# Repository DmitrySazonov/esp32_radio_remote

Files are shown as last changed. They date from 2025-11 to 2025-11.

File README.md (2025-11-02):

# ESP32 Radio Remote

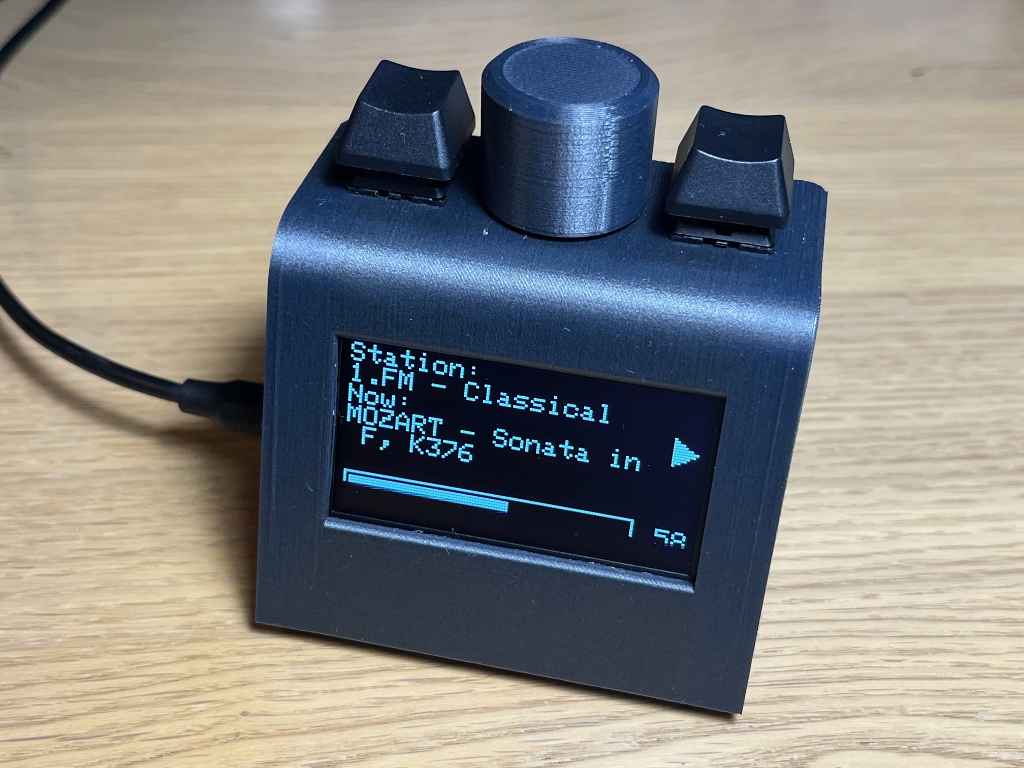
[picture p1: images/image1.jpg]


Small ESP32-based remote for controlling a phone radio/streaming app [Flutter radio](https://github.com/DmitrySazonov/flutter_radio) over HTTP.
It shows station and “now playing” on a 128×64 SSD1306 OLED, has an encoder for volume and play/pause, dedicated Prev/Next buttons, night dimming, and a Screen Off idle timer. A built-in web page lets you configure Wi-Fi and behavior without reflashing.

## Repository Layout

```bash
.
├─ fritzing/     # Fritzing schematic (.fzz) + exported image(s)
├─ stl/          # 3D-printable case parts
└─ esp32-radio-remote.ino  # main Arduino sketch
```

## Features (quick list)

- Encoder: rotate = volume (with optional acceleration), press:
  - single click = Play/Pause
  - rotate while pressed = Station tuning (Prev/Next)
- Buttons: dedicated Prev and Next GPIO buttons
- OLED UI: station title + now playing, volume bar, optional Wi-Fi badge (STA/AP)
- Night mode: dim to a low brightness after inactivity
- Screen Off: fully power down the OLED after a longer timeout
- Web UI (STA/AP): configure Wi-Fi SSID/Password, app host/port/token, scrolling, brightness levels, and more

- Resilience:
  - If Wi-Fi is down: device switches to AP config portal
  - If phone/app is unreachable: shows Phone offline. Retry connection... and retries with growing timeouts (up to 10s), then continues polling

## Hardware

- MCU: ESP32 DevKit (ESP-WROOM-32 or similar)
- Display: SSD1306 128×64 (I²C, address 0x3C)
- Encoder: 2-bit incremental with push button
- Buttons: two momentary buttons for Prev and Next

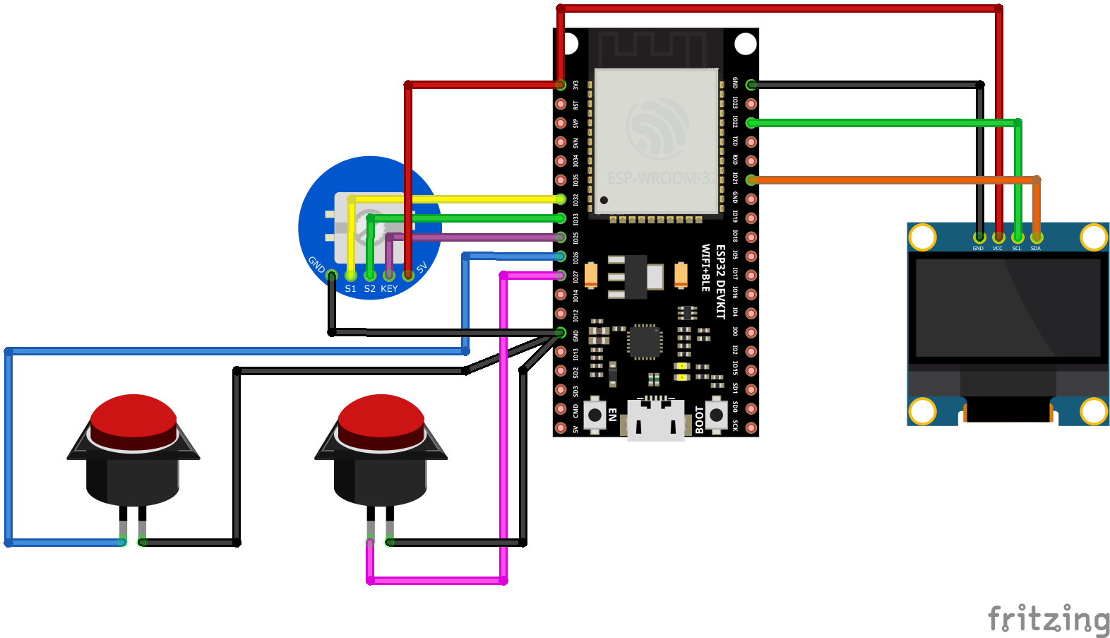
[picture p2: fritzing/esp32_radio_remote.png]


See fritzing/ for exact wiring (.fzz) and a PNG preview.
STL files for the enclosure live in stl/.

### Default pins (can be edited in the sketch):

- Encoder: CLK 32, DT 33, SW 25
- I²C: SDA 21, SCL 22
- Prev/Next: 26, 27 (wired to GND, use INPUT_PULLUP)

## Requirements

- Arduino IDE (2.x recommended)
- ESP32 core by Espressif (Boards Manager)
- Libraries (Library Manager):
  - Adafruit SSD1306
  - Adafruit GFX Library
  - ArduinoJson
  - (Included with ESP32 core: ESPmDNS, DNSServer, ArduinoOTA)

## Installation & Flashing (Arduino IDE)

1. Install ESP32 support

   - File → Preferences → “Additional Boards Manager URLs”: 
   https://raw.githubusercontent.com/espressif/arduino-esp32/gh-pages/package_esp32_index.json
   - Tools → Board → Boards Manager… → install esp32 by Espressif Systems.
     
2. Install libraries
   - Tools → Manage Libraries…
   - Search & install: Adafruit SSD1306, Adafruit GFX Library, ArduinoJson.

3. Open the sketch
    - File → Open… → select esp32-radio-remote.ino in repo root.

4. Select your board & port
   - Tools → Board: choose your ESP32 (e.g., ESP32 Dev Module or your exact variant).
   - Tools → Port: pick the COM/tty of your ESP32.

5. Compile & Upload
   - Sketch → Upload (or the right-arrow button).
   - (Optional) open Tools → Serial Monitor at 115200 baud to see boot logs.

📝 You don’t need to hardcode your Wi-Fi or phone host in the code. After the first boot, the device exposes a Config Portal in AP mode.

## First Boot & Config Portal

 - On the very first boot (or when your configured Wi-Fi is unavailable), the device enters AP mode:
   - SSID: RadioRemote-XXXXXXXX (based on MAC)
   - Password: 12345678
   - Open http://192.168.4.1/
 - After saving, it reboots and tries connecting to your Wi-Fi and your phone app.

Tip: In STA mode you can also try http://radio-remote.local/ or use the device IP (triple-click the encoder to show IP/SSID on OLED).

## Web UI — Settings Explained

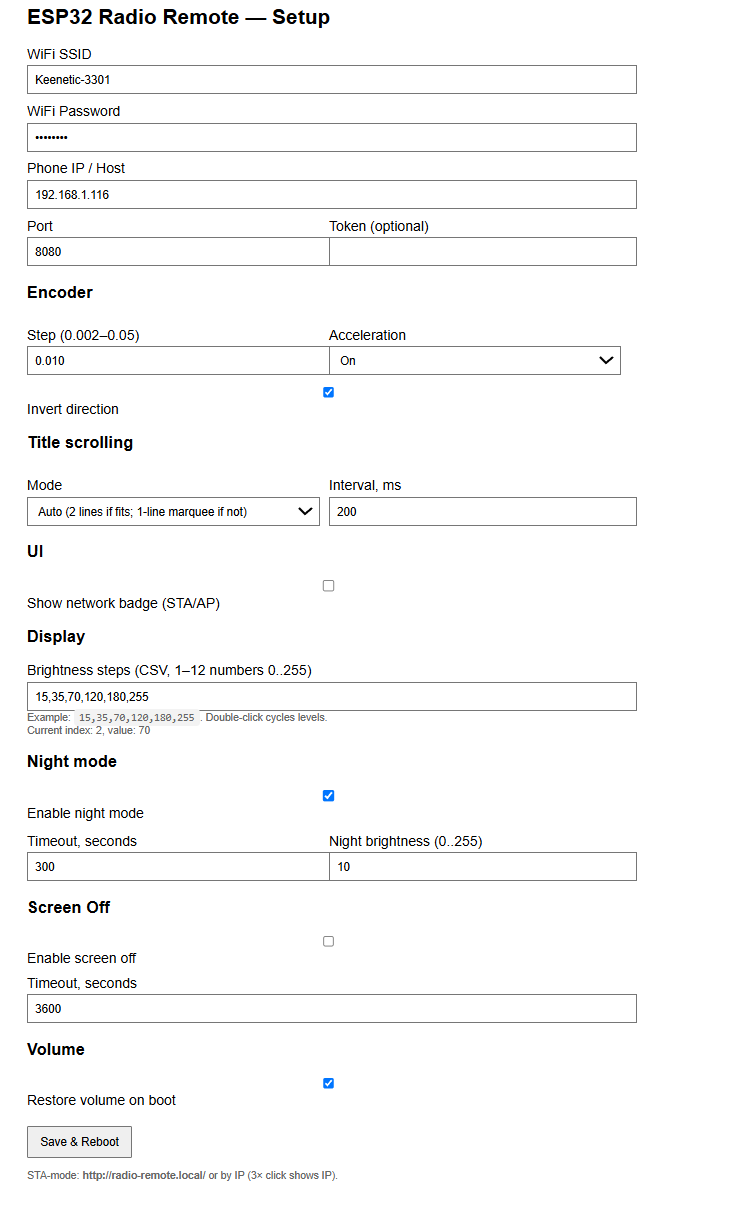
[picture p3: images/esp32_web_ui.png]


Open the device IP in a browser (or http://radio-remote.local/).

### Wi-Fi & Phone App
- WiFi SSID / Password — your network credentials.
- Phone IP / Host — hostname or IP of the phone running the radio/streaming app (the device calls your app’s HTTP endpoints).
- Port — HTTP port of the app (default 8080).
- Token (optional) — if your app expects a token query parameter, it will be appended automatically to every request.

### Encoder
- Step (0.002–0.05) — volume increment per detent (float, e.g. 0.01).
- Acceleration — increases step temporarily when you spin the knob fast.
- Invert direction — flips the volume/tuning direction.

### Title Scrolling
- Mode:
  - Off — never scroll; up to 2 lines are shown if they fit.
  - Auto — if text overflows, use one-line marquee; otherwise 2 lines.
  - Always marquee — always scroll as a single line.
- Interval, ms — scrolling speed (e.g., 200 ms).

### UI
- Show network badge (STA/AP) — small status box in the top-right corner:
  - Mode: STA or AP
  - RSSI indicator (++, + , or - ) if connected

### Display
- Brightness steps (CSV) — comma-separated list of OLED brightness levels (0..255), sorted and deduplicated automatically.
Example: 15,35,70,120,180,255 

Double-click the encoder to cycle levels.

### Night mode
- Enable night mode — after inactivity, dim the screen.
- Timeout, seconds — inactivity period before dimming.
- Night brightness (0..255) — target dim value.

### Screen Off
- Enable screen off — after longer inactivity, power down the OLED.
- Timeout, seconds — inactivity period before complete off (e.g., 3600).

### Volume
- Restore volume on boot — remember last volume and apply after restart.

### Save & Reboot
- Save & Reboot — writes settings to flash and reboots.
A small auto-redirect page returns you to / after the device comes back.

## On-Device Controls (OLED & Buttons)
- Encoder rotate: volume
- Encoder single click: play/pause
- Encoder rotate while held: station tuning (Prev/Next)
- Double click: cycle brightness levels
- Triple click: show network info (IP/SSID) overlay
- Prev/Next buttons: change station immediately

### Status messages on OLED
- If Wi-Fi is unavailable (no IP): device switches to AP mode and shows config hints.
- If phone/app is unreachable (Wi-Fi OK but HTTP fails): display only

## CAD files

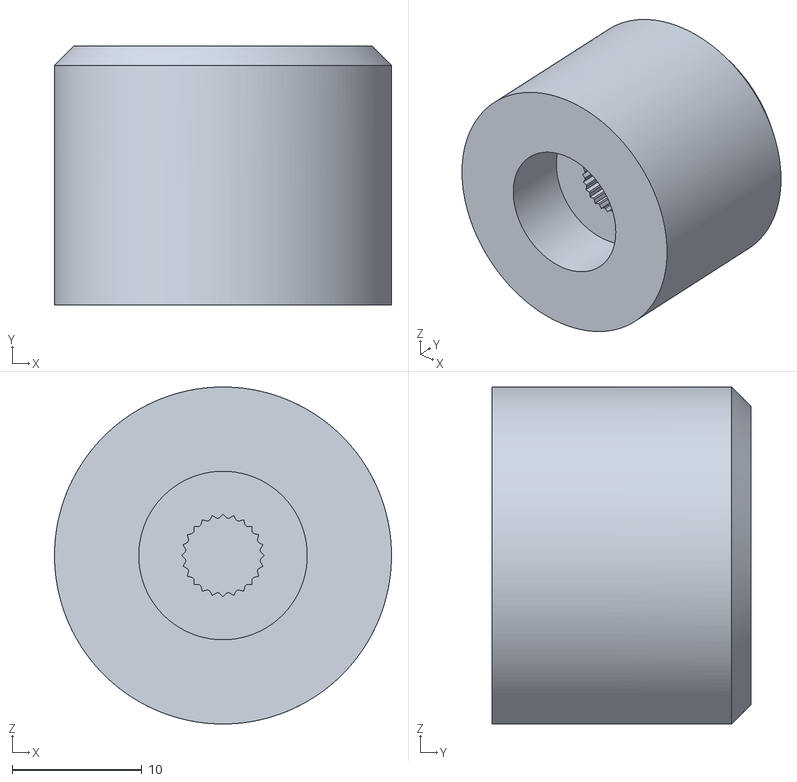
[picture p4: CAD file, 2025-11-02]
stl/encoder-knob.stl
26.0 x 20.0 x 26.0

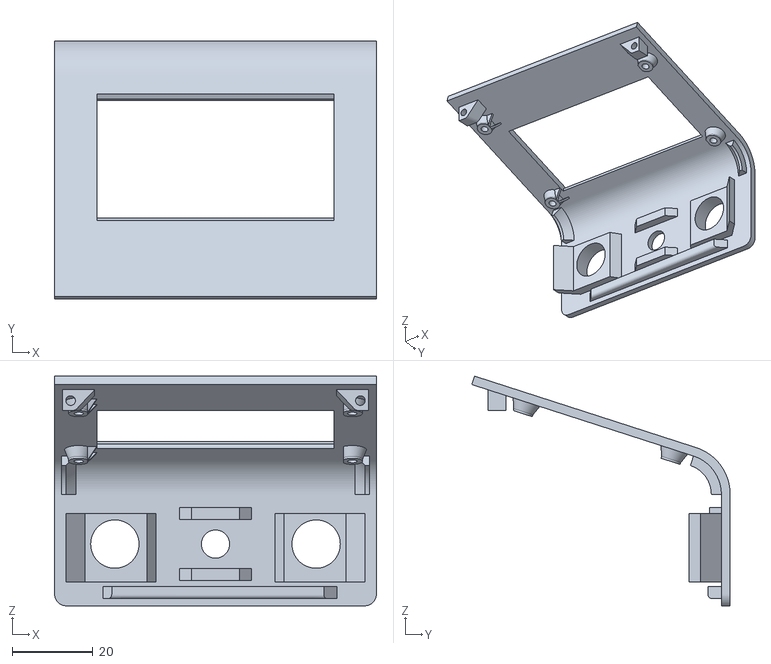
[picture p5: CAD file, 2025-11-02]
stl/cap 1.1.stl
80.0 x 64.2 x 57.1

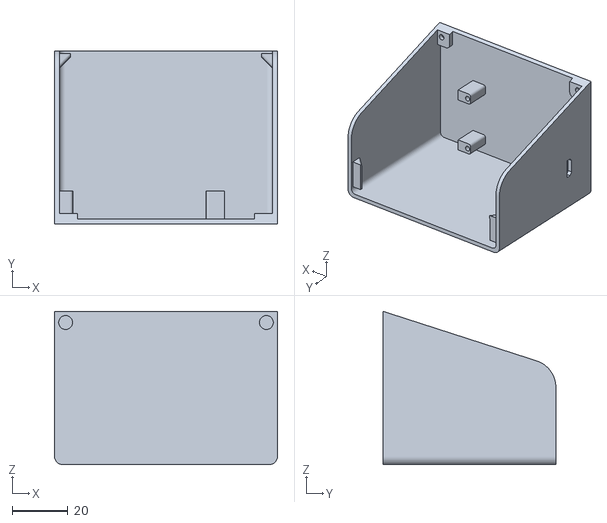
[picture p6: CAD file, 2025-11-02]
stl/case 1.1.stl
80.0 x 62.0 x 55.0

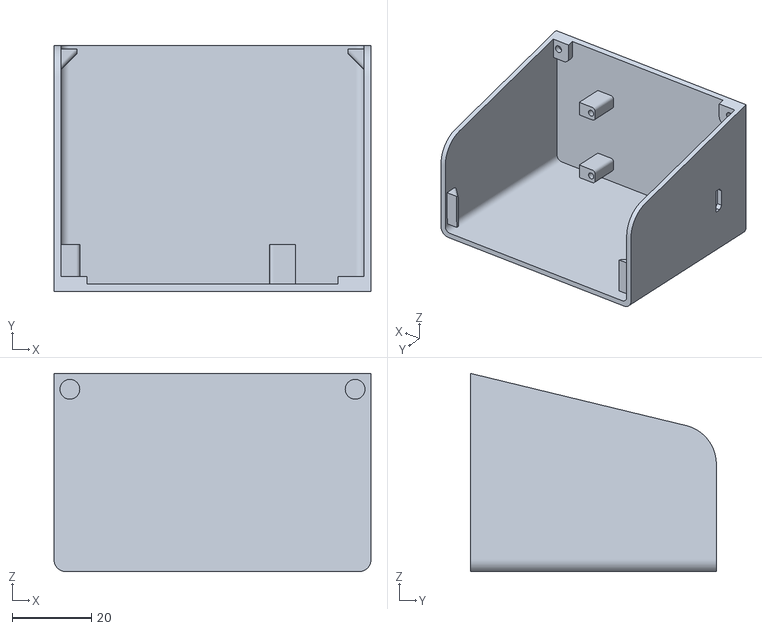
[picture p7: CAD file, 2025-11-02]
stl/case 1.0.stl
80.0 x 62.0 x 50.0

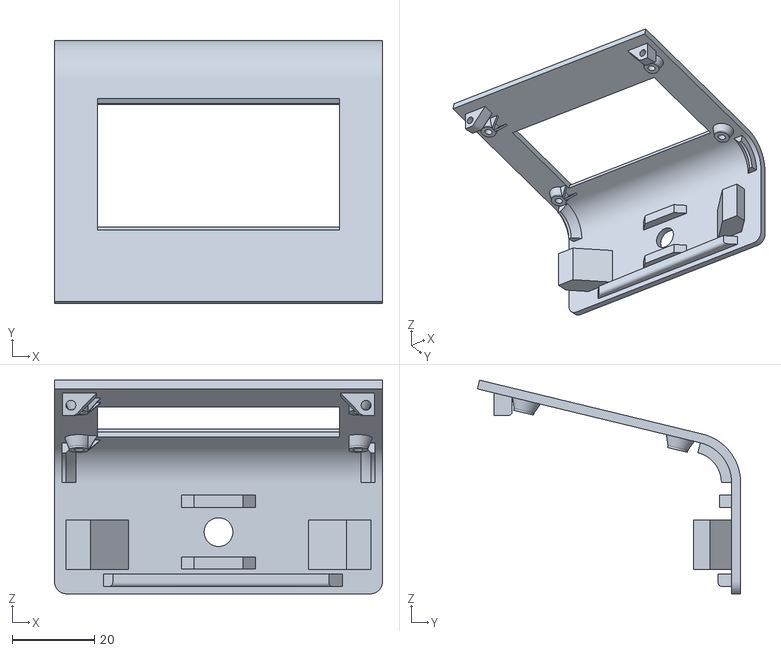
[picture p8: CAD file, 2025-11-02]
stl/cap 1.0.stl
80.0 x 64.2 x 52.1

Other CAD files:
stl/cap 1.2.stl

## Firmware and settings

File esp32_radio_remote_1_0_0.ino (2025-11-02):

/*
 * ESP32 Radio Remote v1.0.0
 * STA веб: http://radio-remote.local/ или http://<IP_ESP32>/
 */

#include <WiFi.h>
#include <WebServer.h>
#include <HTTPClient.h>
#include <Preferences.h>
#include <ArduinoJson.h>
#include <Wire.h>
#include <Adafruit_GFX.h>
#include <Adafruit_SSD1306.h>
#include <DNSServer.h>
#include <ESPmDNS.h>
#include <ArduinoOTA.h>
#include <math.h>

// -------------------- Пины --------------------
#define PIN_ENC_CLK   32
#define PIN_ENC_DT    33
#define PIN_ENC_SW    25
#define I2C_SDA       21
#define I2C_SCL       22
// Кнопки станций:
#define PIN_BTN_PREV  26   // кнопка -> GND, INPUT_PULLUP
#define PIN_BTN_NEXT  27   // кнопка -> GND, INPUT_PULLUP

// -------------------- OLED --------------------
#define SCREEN_WIDTH  128
#define SCREEN_HEIGHT 64
Adafruit_SSD1306 display(SCREEN_WIDTH, SCREEN_HEIGHT, &Wire, -1);

// Символьная ширина строки при TextSize=1
const int TEXT_COLS = 18;

// -------------------- Сеть/портал --------------------
WebServer server(80);
Preferences prefs;
DNSServer dns;

String   cfg_ssid, cfg_pass, cfg_host, cfg_token;
uint16_t cfg_port = 8080;
const byte DNS_PORT = 53;

// --------- Пользовательские настройки ---------
bool     cfg_enc_invert = false;
float    cfg_enc_step   = 0.01f;
bool     cfg_enc_accel  = false;
uint16_t cfg_scroll_ms  = 200;
uint8_t  cfg_scroll_mode= 1;     // 0=Off, 1=Auto, 2=Always marquee
bool     cfg_show_badge = false;

// ---- Яркость по уровням (CSV) ----
#define BR_MAX_STEPS 12
uint8_t  cfg_steps[BR_MAX_STEPS];
uint8_t  cfg_steps_count = 0;
uint8_t  cfg_bri_idx = 0;
uint8_t  cur_brightness = 200;
const char* DEFAULT_STEPS_CSV = "15,35,70,120,180,255";

// Night mode (затемнение)
bool     cfg_night_enable  = true;
uint16_t cfg_night_timeout = 300; // сек
uint8_t  cfg_night_level   = 10;  // 0..255

// Screen Off (полное отключение дисплея)
bool     cfg_scrOff_enable  = false;
uint16_t cfg_scrOff_timeout = 3600; // сек
bool     screenOffActive    = false;

// Restore volume on boot
bool     cfg_restore_vol   = true;
float    last_saved_vol    = 1.0f;

// -------------------- Состояние UI/плеера --------------------
bool   playing = false;
bool   muted   = false;
float  volume  = 1.0f;
String stationName = "-";
String nowTitle    = "-";
int    currentIndex = -1; // из /status, если есть

// Скролл
int titleScroll = 0;
unsigned long lastScrollMs = 0;
unsigned long SCROLL_INTERVAL = 200;

// Overlay (IP, яркость и т.п.)
bool overlayActive = false;
unsigned long overlayUntilMs = 0;
String overlayL1, overlayL2, overlayL3;

// -------------------- Новая логика доступности --------------------
// Wi-Fi реконнект и переход в AP
unsigned long wifiLostSinceMs = 0;
unsigned long nextWifiReconnectMs = 0;
uint8_t wifiReconnectTry = 0;
const unsigned long WIFI_TO_AP_MS = 45000; // сколько держим попытки STA до ухода в AP

// Доступность «телефона» (HTTP-хоста)
bool     phoneOnline = false;
int      hostFailCount = 0;
unsigned long hostTimeoutMs = 2000;              // текущий таймаут HTTP
const unsigned long HOST_TIMEOUT_MIN_MS = 2000;
const unsigned long HOST_TIMEOUT_MAX_MS = 10000;
unsigned long nextHostPollMs = 0;                // когда следующий опрос /status
const unsigned long HOST_SUCCESS_POLL_MS = 2000; // частота при успехах
const float HOST_BACKOFF_FACTOR = 1.7f;          // множитель роста таймаута
const int   HOST_FAILS_TO_SHOW_STATUS = 2;       // после скольких фейлов рисуем "Phone offline"

// Спиннер для статусов
char spinnerChars[4] = {'-', '\\', '|', '/'};
uint8_t spinnerIdx = 0;

// Activity / Night / ScreenOff
unsigned long lastUserActivityMs = 0;
bool nightDimmed = false;

// Блокировка димминга после действий
unsigned long blockNightUntilMs = 0;
const unsigned long NIGHT_BLOCK_WINDOW_MS = 2000;

// -------------------- Кнопка/клики энкодера --------------------
bool btnDown = false;
unsigned long btnDownMs = 0;
const unsigned long BTN_DEBOUNCE = 25;
const unsigned long BTN_LONG_MS  = 750;

uint8_t clickCount = 0;
unsigned long lastClickMs = 0;
const unsigned long MULTI_CLICK_MS = 400;
volatile bool rotatedWhilePressed = false;

// -------------------- Энкодер: детент-декодер --------------------
static const int8_t ENC_DIR_TABLE[16] = {
  0, -1, +1, 0,
  +1, 0,  0, -1,
  -1, 0,  0, +1,
   0, +1, -1, 0
};
volatile uint8_t encState = 0;
volatile int8_t  encPulseAccum = 0;
volatile int8_t  encDetentSteps = 0;
volatile uint32_t encLastEdgeUs = 0;
const uint8_t  ENC_PULSES_PER_DETENT = 4;
const uint32_t ENC_EDGE_DEBOUNCE_US  = 250;
volatile uint32_t lastDetentUs = 0;
void IRAM_ATTR onEncEdge() {
  uint32_t now = micros();
  if (now - encLastEdgeUs < ENC_EDGE_DEBOUNCE_US) return;
  encLastEdgeUs = now;
  uint8_t a = (uint8_t)digitalRead(PIN_ENC_CLK);
  uint8_t b = (uint8_t)digitalRead(PIN_ENC_DT);
  uint8_t ab = (a << 1) | b;
  encState = ((encState << 2) | ab) & 0x0F;
  int8_t dir = ENC_DIR_TABLE[encState];
  if (dir == 0) return;
  encPulseAccum += dir;
  if (encPulseAccum >= ENC_PULSES_PER_DETENT) {
    encPulseAccum = 0; encDetentSteps += 1; lastDetentUs = now;
  } else if (encPulseAccum <= -ENC_PULSES_PER_DETENT) {
    encPulseAccum = 0; encDetentSteps -= 1; lastDetentUs = now;
  }
}

// -------------------- Громкость: пакетная отправка --------------------
float pendingVolume = 1.0f;
unsigned long lastVolSendMs = 0;
const unsigned long VOL_SEND_DEBOUNCE_MS = 60;

// -------------------- Очередь переключений станций (для вращения с зажатием) --------------------
volatile int stationMoveAccum = 0;          // >0 -> next, <0 -> prev
unsigned long lastStationSendMs = 0;
const unsigned long STATION_STEP_MS = 70;   // пауза между командами

// -------------------- Кнопки Prev/Next --------------------
const unsigned long BTN_ST_DEBOUNCE = 25;
bool btnPrevWas = true; // INPUT_PULLUP -> покой HIGH
bool btnNextWas = true;
unsigned long btnPrevChangeMs = 0;
unsigned long btnNextChangeMs = 0;

// -------------------- Прототипы --------------------
void startWiFiOrAP();
void startConfigPortal();
void startMdnsOta();
void setupHttpRoutes();
void handleRoot();
void handleSave();
void drawScreen();
void drawWifiBadge();
void drawOverlay();
void fetchStatusTry(); // ОДНА попытка опроса с текущим таймаутом/бэкоффом
void sendPlayPause();
void sendMuteToggle();
void sendNext();
void sendPrev();
bool sendVolumeOnce(float v);
void sendVolume(float v);
String buildUrl(const String& path);
void wifiToAP();
bool needsMarqueeOneLine(const String& s);
void showNetworkInfoOverlay(unsigned long ms = 3500);
void markActivity();
void ensureAwake();

// Яркость/экран
static inline uint8_t gammaMap(uint8_t v);
void applyBrightness(uint8_t v);
void cycleBrightness();
void oledDisplayOn();
void oledDisplayOff();

// Ступени яркости
bool parseStepsCSV(const String& csv, uint8_t out[], uint8_t &count);
String stepsToCSV(const uint8_t arr[], uint8_t count);
void loadBrightnessSteps();
uint8_t nearestStepIndex(uint8_t raw);

// Helpers для вывода NOW
void drawNowBlock(const String& s);

// ---- UTF-8 -> ASCII нормализация пунктуации ----
String sanitizeUtf8ToAscii(const String& in) {
  String out; out.reserve(in.length());
  for (size_t i = 0; i < in.length(); ) {
    uint8_t c = (uint8_t)in[i];
    if (c < 0x80) { out += (char)c; i++; continue; } // ASCII
    // E2 80 xx: ‘ ’ “ ” – — …
    if (i + 2 < in.length() &&
        (uint8_t)in[i]   == 0xE2 &&
        (uint8_t)in[i+1] == 0x80) {
      uint8_t t = (uint8_t)in[i+2];
      if (t == 0x98 || t == 0x99) { out += '\''; i += 3; continue; }  // ‘ ’ -> '
      if (t == 0x9C || t == 0x9D) { out += '\"'; i += 3; continue; }  // “ ” -> "
      if (t == 0x93 || t == 0x94) { out += '-';  i += 3; continue; }  // – — -> -
      if (t == 0xA6)              { out += "...";i += 3; continue; }  // … -> ...
    }
    // NBSP: C2 A0
    if (i + 1 < in.length() &&
        (uint8_t)in[i]   == 0xC2 &&
        (uint8_t)in[i+1] == 0xA0) { out += ' '; i += 2; continue; }
    // Прочие non-ASCII — пропускаем
    i += ((c & 0xE0) == 0xC0) ? 2 : ((c & 0xF0) == 0xE0) ? 3 : 1;
  }
  return out;
}

// -------------------- Setup --------------------
void setup() {
  pinMode(PIN_ENC_CLK, INPUT_PULLUP);
  pinMode(PIN_ENC_DT,  INPUT_PULLUP);
  pinMode(PIN_ENC_SW,  INPUT_PULLUP);
  attachInterrupt(digitalPinToInterrupt(PIN_ENC_CLK), onEncEdge, CHANGE);
  attachInterrupt(digitalPinToInterrupt(PIN_ENC_DT),  onEncEdge, CHANGE);

  pinMode(PIN_BTN_PREV, INPUT_PULLUP);
  pinMode(PIN_BTN_NEXT, INPUT_PULLUP);

  Wire.begin(I2C_SDA, I2C_SCL);
  display.begin(SSD1306_SWITCHCAPVCC, 0x3C);
  display.clearDisplay();
  display.setTextSize(1);
  display.setTextColor(SSD1306_WHITE);
  display.setCursor(0,0);
  display.println("Radio Remote v1.0.0");
  display.display();

  prefs.begin("cfg", false);
  cfg_ssid  = prefs.getString("ssid", "");
  cfg_pass  = prefs.getString("pass", "");
  cfg_host  = prefs.getString("host", "");
  cfg_port  = prefs.getUShort("port", 8080);
  cfg_token = prefs.getString("token", "");

  cfg_enc_invert   = prefs.getBool ("enc_inv", false);
  cfg_enc_step     = prefs.getFloat("enc_step", 0.01f);
  cfg_enc_accel    = prefs.getBool ("enc_acc", false);
  cfg_scroll_ms    = prefs.getUShort("scr_ms", 200);
  cfg_scroll_mode  = prefs.getUChar ("scr_mode", 1);
  cfg_show_badge   = prefs.getBool ("badge", false);

  // Screen Off
  cfg_scrOff_enable  = prefs.getBool ("scrOff_en", false);
  cfg_scrOff_timeout = prefs.getUShort("scrOff_to", 3600);

  // Яркость
  loadBrightnessSteps();
  cfg_bri_idx = prefs.getUChar("bri_idx", 0);
  if (cfg_bri_idx >= cfg_steps_count) cfg_bri_idx = 0;

  uint8_t legacy_raw = prefs.getUChar("bright_raw", 255);
  if (legacy_raw != 255) {
    cfg_bri_idx = nearestStepIndex(legacy_raw);
    prefs.remove("bright_raw");
    prefs.putUChar("bri_idx", cfg_bri_idx);
  }
  cur_brightness = cfg_steps[cfg_bri_idx];
  applyBrightness(cur_brightness);
  oledDisplayOn(); // на всякий

  // Night mode
  cfg_night_enable  = prefs.getBool ("night_en", true);
  cfg_night_timeout = prefs.getUShort("night_to", 300);
  cfg_night_level   = prefs.getUChar ("night_lvl", 10);
  if (cfg_night_level > 255) cfg_night_level = 255;

  // Громкость
  cfg_restore_vol   = prefs.getBool ("restore_vol", true);
  last_saved_vol    = prefs.getFloat("last_vol", 1.0f);
  if (last_saved_vol < 0.0f || last_saved_vol > 1.0f) last_saved_vol = 1.0f;

  // Валидация
  if (cfg_enc_step   < 0.002f) cfg_enc_step   = 0.002f;
  if (cfg_enc_step   > 0.05f)  cfg_enc_step   = 0.05f;
  if (cfg_scroll_ms  < 50)     cfg_scroll_ms  = 50;
  if (cfg_scroll_ms  > 2000)   cfg_scroll_ms  = 2000;
  if (cfg_scroll_mode > 2)     cfg_scroll_mode= 1;
  if (cfg_scrOff_timeout < 30) cfg_scrOff_timeout = 30;
  if (cfg_scrOff_timeout > 86400) cfg_scrOff_timeout = 86400;

  SCROLL_INTERVAL = cfg_scroll_ms;

  startWiFiOrAP();
  drawScreen();

  lastUserActivityMs = millis();
  pendingVolume = volume;

  // Инициализация статусов
  phoneOnline = false;
  hostTimeoutMs = HOST_TIMEOUT_MIN_MS;
  nextHostPollMs = millis(); // сразу пробовать
}

// -------------------- Loop --------------------
void loop() {
  if (WiFi.getMode() == WIFI_AP) dns.processNextRequest();
  server.handleClient();
  ArduinoOTA.handle();

  unsigned long nowMs = millis();

  // ---------------- Wi-Fi состояние ----------------
  if (WiFi.status() != WL_CONNECTED) {
    if (wifiLostSinceMs == 0) wifiLostSinceMs = nowMs;

    // экспоненциальный бэкофф реконнекта
    if (nowMs >= nextWifiReconnectMs) {
      WiFi.reconnect();
      wifiReconnectTry = min<uint8_t>(wifiReconnectTry + 1, 10);
      uint32_t backoff = 300 + (uint32_t)pow(1.8, wifiReconnectTry) * 100;
      nextWifiReconnectMs = nowMs + backoff;
    }

    // Долго нет Wi-Fi -> AP
    if ((nowMs - wifiLostSinceMs) > WIFI_TO_AP_MS) {
      wifiToAP();
      // В AP мы не делаем никаких HTTP-попыток
    }

  } else {
    // Был коннект — сбросить счётчики
    wifiLostSinceMs = 0;
    wifiReconnectTry = 0;

    // ---------------- HTTP-хост («телефон») ----------------
    if (nowMs >= nextHostPollMs && WiFi.getMode() == WIFI_STA) {
      fetchStatusTry(); // корректирует nextHostPollMs/hostTimeoutMs/флаги
      if (!overlayActive && !screenOffActive) drawScreen();
    }
  }

  // Прокрутка NOW + спиннер
  if (nowMs - lastScrollMs >= SCROLL_INTERVAL) {
    lastScrollMs = nowMs;
    bool overflow = needsMarqueeOneLine(nowTitle);
    bool scrollActive = (cfg_scroll_mode == 2) || (cfg_scroll_mode == 1 && overflow);
    if (scrollActive && nowTitle.length() > 0) {
      int ringLen = nowTitle.length() + 3;
      if (ringLen <= 0) ringLen = 1;
      titleScroll = (titleScroll + 1) % ringLen;
      if (!overlayActive && !screenOffActive) drawScreen();
    } else titleScroll = 0;
    spinnerIdx = (spinnerIdx + 1) & 3;
  }

  // Overlay TTL
  if (overlayActive && nowMs >= overlayUntilMs) { overlayActive = false; if (!screenOffActive) drawScreen(); }

  // Night mode (затемнение, но не Screen Off)
  if (cfg_night_enable) {
    if (!nightDimmed) {
      bool gestureActive = btnDown || rotatedWhilePressed;
      if (!gestureActive && nowMs >= blockNightUntilMs) {
        if ((nowMs - lastUserActivityMs) > (uint32_t)cfg_night_timeout * 1000UL) {
          applyBrightness(cfg_night_level);
          nightDimmed = true;
        }
      }
    }
  }

  // Screen Off (полное отключение дисплея)
  if (cfg_scrOff_enable) {
    if (!screenOffActive) {
      bool gestureActive = btnDown || rotatedWhilePressed;
      if (!gestureActive && nowMs >= blockNightUntilMs) {
        if ((nowMs - lastUserActivityMs) > (uint32_t)cfg_scrOff_timeout * 1000UL) {
          oledDisplayOff();
          screenOffActive = true;
        }
      }
    }
  }

  // Кнопки Prev/Next (дребезг)
  bool prevNow = (digitalRead(PIN_BTN_PREV) == LOW);
  bool nextNow = (digitalRead(PIN_BTN_NEXT) == LOW);

  if (prevNow != btnPrevWas && (nowMs - btnPrevChangeMs) > BTN_ST_DEBOUNCE) {
    btnPrevWas = prevNow; btnPrevChangeMs = nowMs;
    if (prevNow) { sendPrev(); if (!overlayActive && !screenOffActive) drawScreen(); markActivity(); ensureAwake(); }
  }
  if (nextNow != btnNextWas && (nowMs - btnNextChangeMs) > BTN_ST_DEBOUNCE) {
    btnNextWas = nextNow; btnNextChangeMs = nowMs;
    if (nextNow) { sendNext(); if (!overlayActive && !screenOffActive) drawScreen(); markActivity(); ensureAwake(); }
  }

  // Мультиклики энкодера
  bool sw = (digitalRead(PIN_ENC_SW) == LOW);
  static bool btnWas = false;
  static unsigned long btnChangeMs = 0;
  if (sw != btnWas && (nowMs - btnChangeMs) > BTN_DEBOUNCE) {
    btnWas = sw; btnChangeMs = nowMs;
    if (sw) { btnDown = true; btnDownMs = nowMs; rotatedWhilePressed = false; }
    else {
      bool wasLong = (nowMs - btnDownMs) >= BTN_LONG_MS; btnDown = false;
      if (rotatedWhilePressed) { rotatedWhilePressed = false; markActivity(); ensureAwake(); }
      else {
        if (wasLong) { clickCount = 0; sendMuteToggle(); markActivity(); ensureAwake(); }
        else { clickCount++; lastClickMs = nowMs; markActivity(); ensureAwake(); }
      }
    }
  }
  if (clickCount > 0 && (nowMs - lastClickMs) > MULTI_CLICK_MS) {
    uint8_t n = clickCount; clickCount = 0;
    if (n >= 3) { showNetworkInfoOverlay(3500); markActivity(); ensureAwake(); }
    else if (n == 2) { markActivity(); ensureAwake(); cycleBrightness(); }
    else if (n == 1) { sendPlayPause(); markActivity(); ensureAwake(); }
  }

  // Энкодер детенты
  int8_t detents;
  noInterrupts(); detents = encDetentSteps; encDetentSteps = 0; interrupts();
  if (detents != 0) {
    int dir = cfg_enc_invert ? -1 : 1;
    int move = detents * dir;

    if (digitalRead(PIN_ENC_SW) == LOW || btnDown) {
      rotatedWhilePressed = true;
      stationMoveAccum += move;
      markActivity(); ensureAwake();
    } else {
      if (cfg_enc_accel) {
        uint32_t usSince = micros() - lastDetentUs;
        int accel = (usSince < 1200) ? 3 : (usSince < 2500) ? 2 : 1;
        move *= accel;
      }
      pendingVolume = constrain(pendingVolume + cfg_enc_step * move, 0.0f, 1.0f);
      markActivity(); ensureAwake();
    }
  }

  // Очередь станций (для вращения)
  if (stationMoveAccum != 0 && (nowMs - lastStationSendMs) >= STATION_STEP_MS) {
    if (stationMoveAccum > 0) { sendNext(); stationMoveAccum -= 1; }
    else                      { sendPrev(); stationMoveAccum += 1; }
    lastStationSendMs = nowMs;
    if (!overlayActive && !screenOffActive) drawScreen();
  }

  // Громкость — отправка пакетно
  if (fabs(pendingVolume - volume) >= (cfg_enc_step * 0.5f)) {
    if ((nowMs - lastVolSendMs) >= VOL_SEND_DEBOUNCE_MS) {
      if (sendVolumeOnce(pendingVolume)) {
        volume = pendingVolume;
        prefs.putFloat("last_vol", volume);
      }
      lastVolSendMs = nowMs;
      if (!overlayActive && !screenOffActive) drawScreen();
    }
  }

  delay(3);
}

// -------------------- Wi-Fi & портал --------------------
void startWiFiOrAP() {
  if (cfg_ssid.length() > 0 && cfg_host.length() > 0) {
    WiFi.mode(WIFI_STA);
    WiFi.begin(cfg_ssid.c_str(), cfg_pass.c_str());

    display.clearDisplay();
    display.setCursor(0,0);
    display.println("WiFi connect...");
    display.println(cfg_ssid);
    display.display();

    unsigned long t0 = millis();
    while (WiFi.status() != WL_CONNECTED && millis() - t0 < 12000) {
      delay(250); display.print("."); display.display();
    }
    if (WiFi.status() == WL_CONNECTED) {
      display.println(); display.println("OK: " + WiFi.localIP().toString()); display.display();
      delay(500);
      startMdnsOta();
      setupHttpRoutes(); server.begin();

      if (cfg_restore_vol) {
        float v = constrain(last_saved_vol, 0.0f, 1.0f);
        if (sendVolumeOnce(v)) { volume = v; pendingVolume = v; }
      }
      nextHostPollMs = millis(); // сразу пробуем хост
      return;
    }
  }
  startConfigPortal();
}

void startConfigPortal() {
  WiFi.mode(WIFI_AP);
  String apName = "RadioRemote-" + String((uint32_t)ESP.getEfuseMac(), HEX);
  apName.toUpperCase();
  WiFi.softAP(apName.c_str(), "12345678");
  IPAddress ip = WiFi.softAPIP();
  dns.start(DNS_PORT, "*", ip);

  setupHttpRoutes(); server.begin();

  display.clearDisplay();
  display.setCursor(0,0);
  display.println("CONFIG MODE");
  display.println("AP: " + apName);
  display.println("PW: 12345678");
  display.println("Open: 192.168.4.1");
  display.display();
}

void startMdnsOta() {
  if (MDNS.begin("radio-remote")) MDNS.addService("http","tcp",80);
  ArduinoOTA.setHostname("radio-remote");
  ArduinoOTA.begin();
}

// -------------------- HTTP-маршруты --------------------
void setupHttpRoutes() {
  server.on("/", handleRoot);
  server.on("/save", HTTP_POST, handleSave);
}
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
